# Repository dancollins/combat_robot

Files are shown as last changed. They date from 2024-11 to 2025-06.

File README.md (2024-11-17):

## Firmware

### Prerequisites

1. [Miniconda](https://docs.anaconda.com/miniconda/), and an environment with Python 3.10
2. [Zephyr SDK](https://docs.zephyrproject.org/latest/develop/toolchains/zephyr_sdk.html)
3. [CMake](https://cmake.org/download/)
4. [Ninja](https://ninja-build.org/)

Now you can run a few commands to get more dependancies:

    cd <repo>/zephyr-workspace
    west update
    cd zephyr/scripts
    pip install -r requirements.txt
    cd <repo>/zephyr-workspace

### Building

There's no actual firmware or board yet - so in the mean time here's a generic
build for the included minimal sample.

    west build --pristine --board nucleo_l412rb_p firmware

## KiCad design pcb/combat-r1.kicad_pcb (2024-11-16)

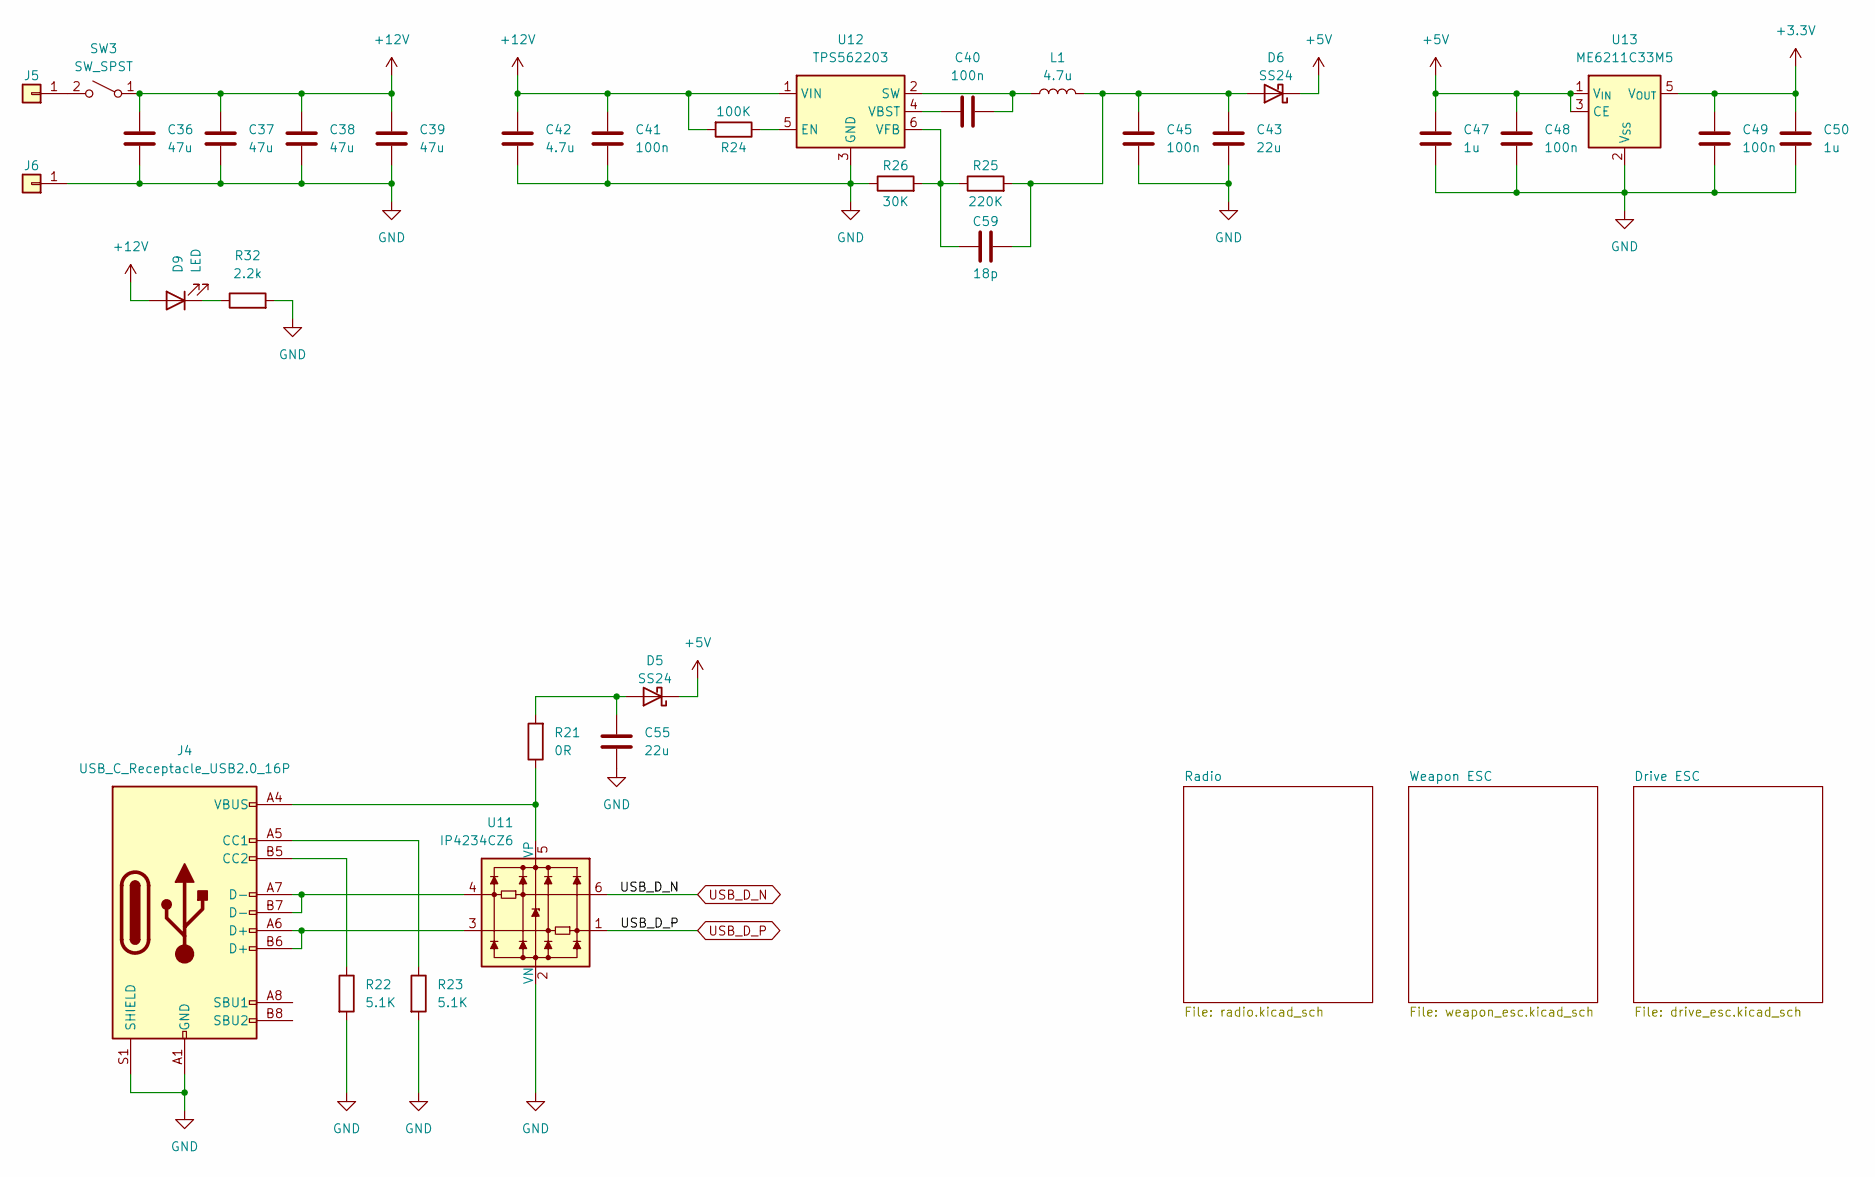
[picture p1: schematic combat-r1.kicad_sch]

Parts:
C36, C37, C38, C39: 47u; C_1210_3225Metric; LCSC C90142
C40, C41, C45, C48: 100n; C_0603_1608Metric; LCSC C1591
C42: 4.7u; C_0603_1608Metric; LCSC C69335
C43, C55: 22u; C_0805_2012Metric; LCSC C602037
C47: 1u; C_0603_1608Metric; Voltage 10V; LCSC C29936
C49: 100n; C_0603_1608Metric; Voltage 10V; LCSC C1591
C50: 1u; C_0603_1608Metric; LCSC C29936
C59: 18p; C_0603_1608Metric; LCSC C1647
D5, D6: SS24; D_SMA; LCSC C6069590
D9: LED; LED_0603_1608Metric; LCSC C434425
J4: USB_C_Receptacle_USB2.0_16P; USB_C_Receptacle_GCT_USB4105-xx-A_16P_TopMnt_Horizontal; LCSC C165948
J5, J6: Conn_01x01; SolderWire-1sqmm_1x01_D1.4mm_OD3.9mm
L1: 4.7u; L_Sunlord_MWSA0624S; LCSC C408433
R21: 0R; R_0603_1608Metric; LCSC C21189
R22, R23: 5.1K; R_0603_1608Metric; LCSC C23186
R24: 100K; R_0603_1608Metric; LCSC C25803
R25: 220K; R_0603_1608Metric; LCSC C22961
R26: 30K; R_0603_1608Metric; LCSC C22984
R32: 2.2k; R_0603_1608Metric; LCSC C4190
SW3: SW_SPST; m3-power-switch; LCSC C7528081
U11: IP4234CZ6; SC-74-6_1.55x2.9mm_P0.95mm; LCSC C551509
U12: TPS562203; SOT-563; LCSC C22445511
U13: ME6211C33M5; SOT-23-5; LCSC C82942

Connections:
+3.3V: C49.1, C50.1, U13.5 (V_{OUT}); also elsewhere on the board
+5V: C47.1, C48.1, D5.1 (K), D6.1 (K), U13.1 (V_{IN}), U13.3 (CE)
+12V: C36.1, C37.1, C38.1, C39.1, C41.1, C42.1, D9.2 (A), R24.2, SW3.1 (A), U12.1 (VIN); also elsewhere on the board
GND: C36.2, C37.2, C38.2, C39.2, C41.2, C42.2, C43.2, C45.2, C47.2, C48.2, C49.2, C50.2, C55.2, J4.A1 (GND), J4.A12 (GND), J4.B1 (GND), J4.B12 (GND), J4.S1 (SHIELD), J6.1, R22.2, R23.2, R26.1, R32.2, U11.2 (VN), U12.3 (GND), U13.2 (V_{SS}); also elsewhere on the board
unnamed: C55.1, D5.2 (A), R21.2
unnamed: C43.1, C45.1, C59.1, D6.2 (A), L1.2, R25.2
unnamed: D9.1 (K), R32.1
unnamed: J4.A5 (CC1), R23.1
unnamed: J4.B5 (CC2), R22.1
unnamed: J4.A6 (D+), J4.B6 (D+), U11.3
unnamed: J4.A7 (D-), J4.B7 (D-), U11.4
unnamed: J5.1, SW3.2 (B)
unnamed: J4.A4 (VBUS), J4.A9 (VBUS), J4.B4 (VBUS), J4.B9 (VBUS), R21.1, U11.5 (VP)
unnamed: R24.1, U12.5 (EN)
unnamed: C40.1, L1.1, U12.2 (SW)
unnamed: C40.2, U12.4 (VBST)
unnamed: C59.2, R25.1, R26.2, U12.6 (VFB)
USB_D_N: U11.6; also elsewhere on the board
USB_D_P: U11.1; also elsewhere on the board

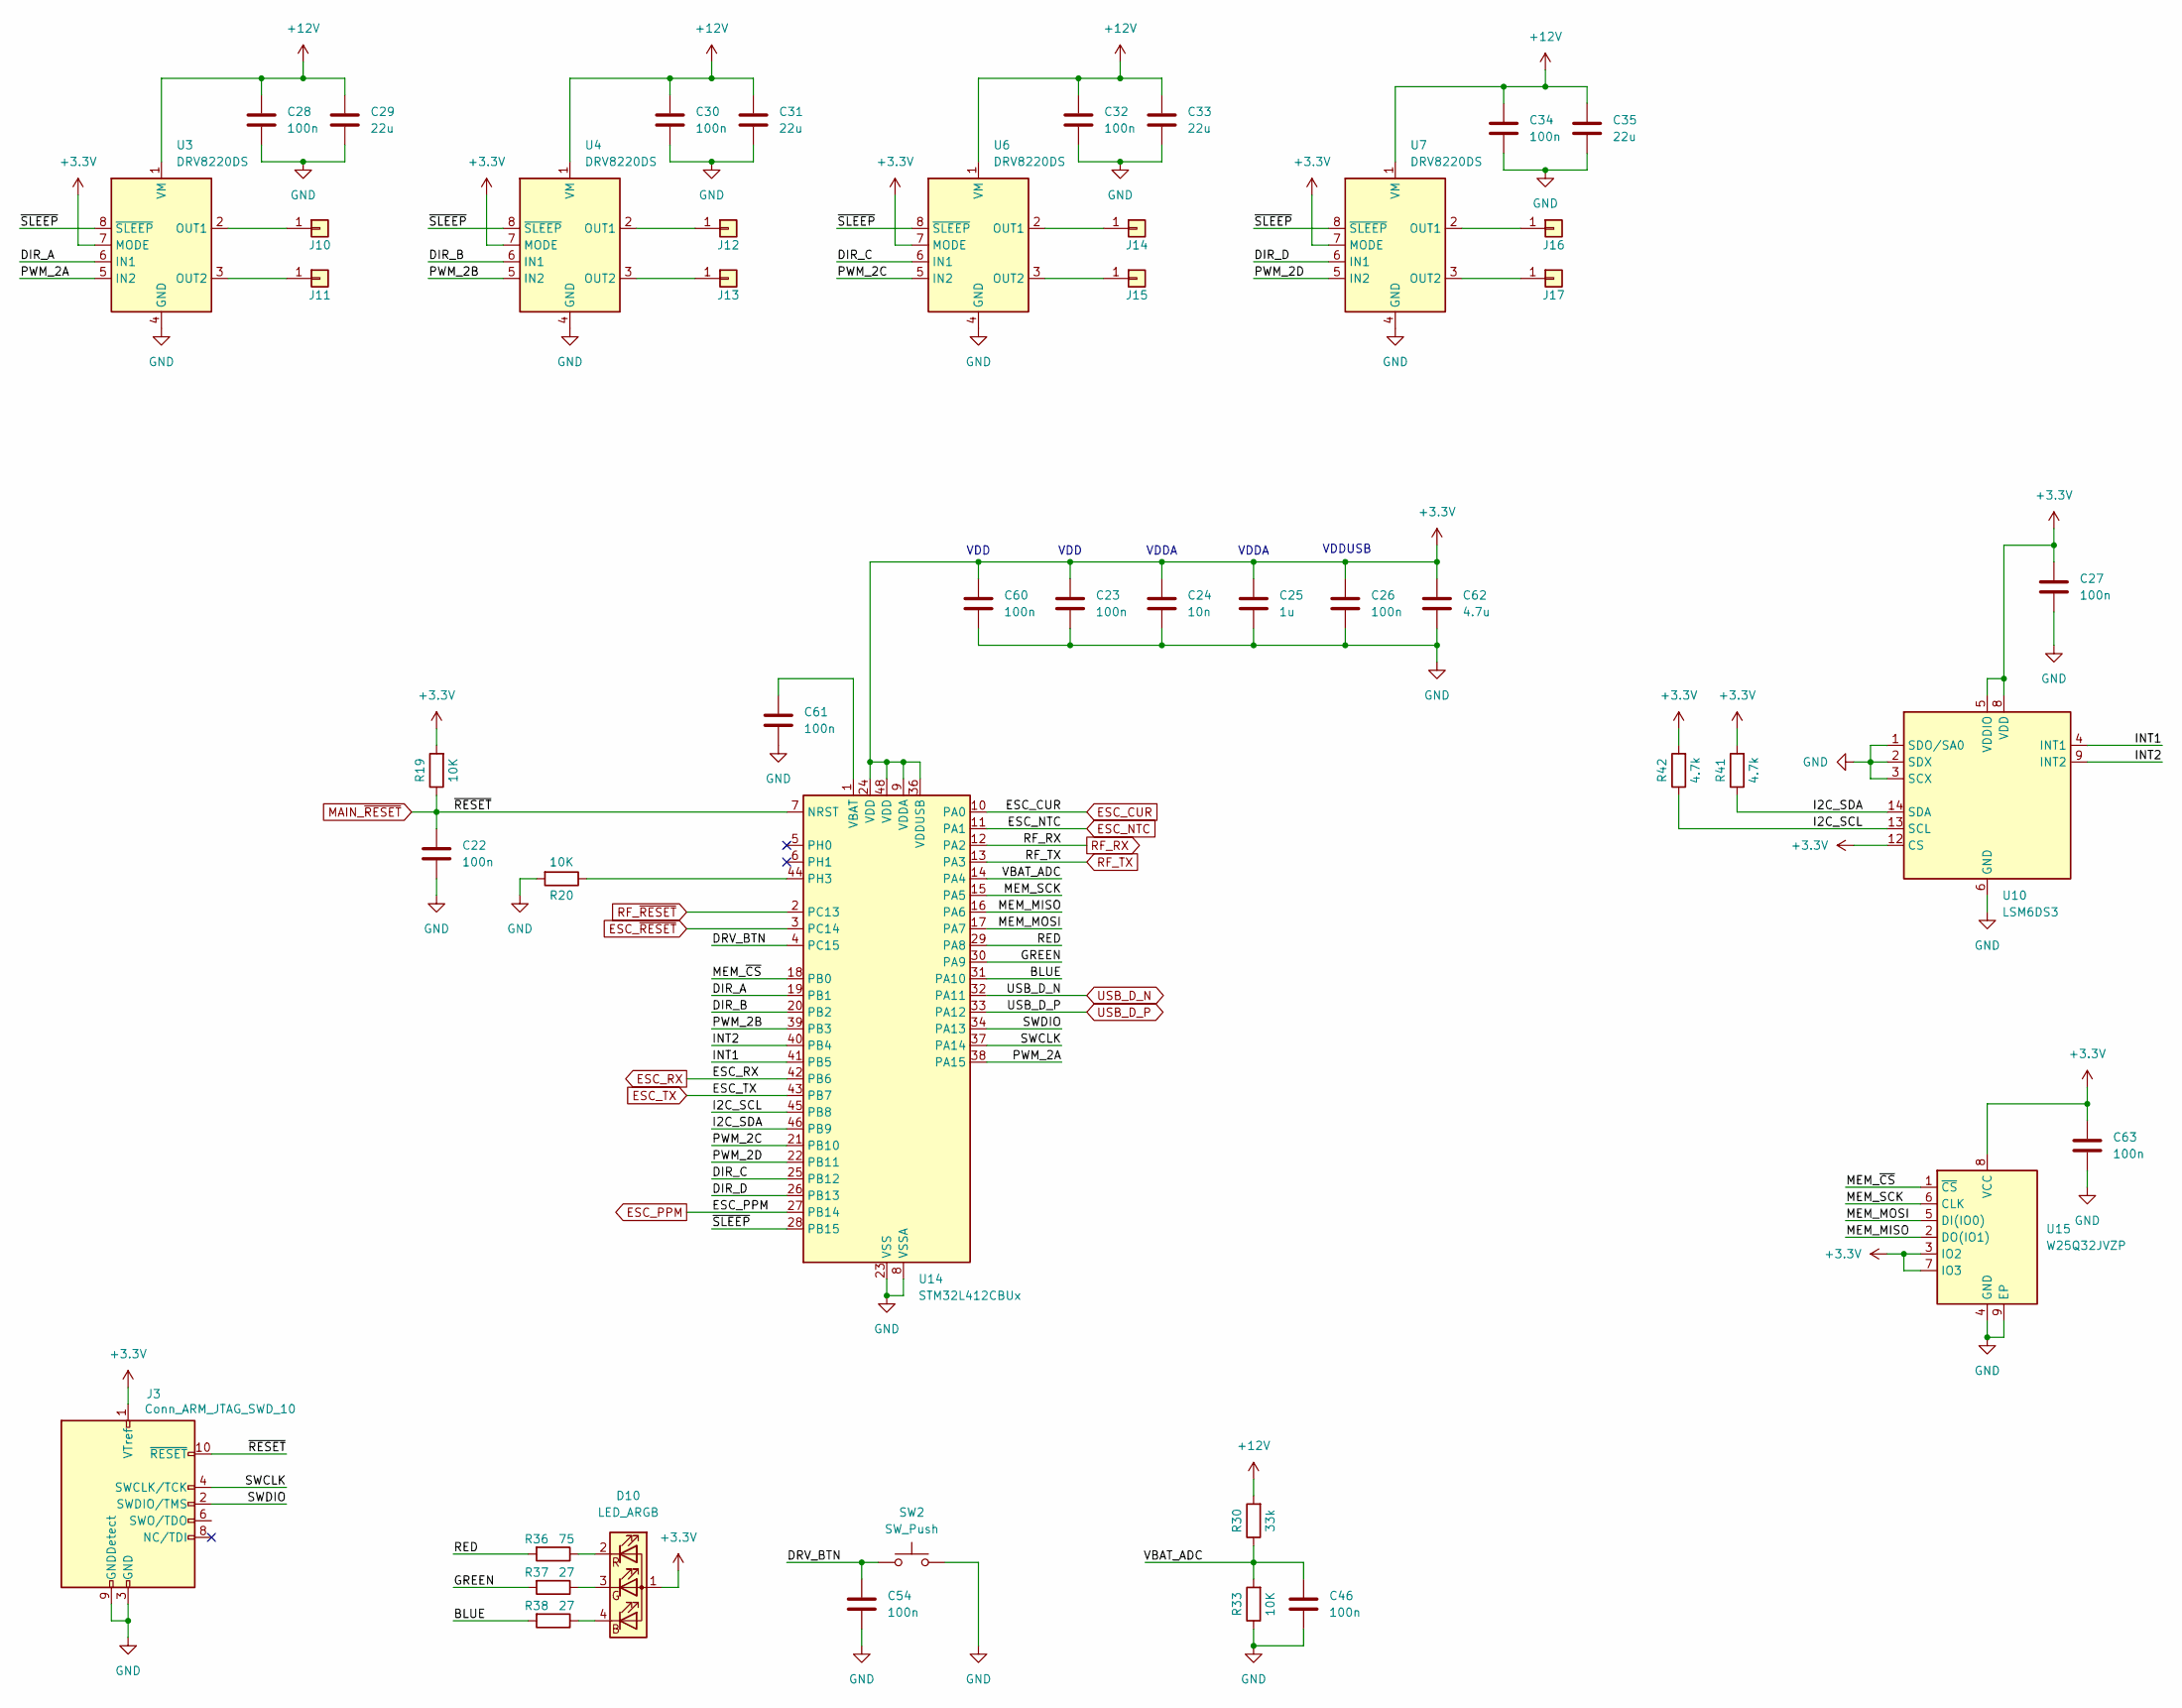
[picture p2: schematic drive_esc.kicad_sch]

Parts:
C22, C23, C26, C27, C28, C30, C32, C34, C46, C54, C60, C61, C63: 100n; C_0603_1608Metric; LCSC C1591
C24: 10n; C_0603_1608Metric; LCSC C1589
C25: 1u; C_0603_1608Metric; LCSC C29936
C29, C31, C33, C35: 22u; C_1206_3216Metric; LCSC C342620
C62: 4.7u; C_0603_1608Metric; LCSC C69335
D10: LED_ARGB; LED_LiteOn_LTST-C19HE1WT; LCSC C458749
J3: Conn_ARM_JTAG_SWD_10; PinHeader_2x05_P1.27mm_Vertical_SMD
J10, J11, J12, J13, J14, J15, J16, J17: Conn_01x01; SolderWire-1sqmm_1x01_D1.4mm_OD3.9mm
R19, R20, R33: 10K; R_0603_1608Metric; LCSC C25804
R30: 33k; R_0603_1608Metric; LCSC C4216
R36: 75; R_0603_1608Metric; LCSC C4275
R37, R38: 27; R_0603_1608Metric; LCSC C25190
R41, R42: 4.7k; R_0603_1608Metric; LCSC C23162
SW2: SW_Push; SW_SPST_Omron_B3FS-100xP; LCSC C4364467
U3, U4, U6, U7: DRV8220DS; WSON-8-1EP_2x2mm_P0.5mm_EP0.9x1.6mm; LCSC C3681269
U10: LSM6DS3; LGA-14_3x2.5mm_P0.5mm_LayoutBorder3x4y; LCSC C95230
U14: STM32L412CBUx; QFN-48-1EP_7x7mm_P0.5mm_EP5.6x5.6mm; Mouser 511-STM32L412C8U6
U15: W25Q32JVZP; WSON-8-1EP_6x5mm_P1.27mm_EP3.4x4.3mm; LCSC C571260

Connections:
+3.3V: C23.1, C24.1, C25.1, C26.1, C27.1, C60.1, C62.1, C63.1, D10.1 (A), J3.1 (VTref), R19.2, R41.2, R42.2, U3.7 (MODE), U4.7 (MODE), U6.7 (MODE), U7.7 (MODE), U10.5 (VDDIO), U10.8 (VDD), U10.12 (CS), U14.9 (VDDA), U14.24 (VDD), U14.36 (VDDUSB), U14.48 (VDD), U15.3 (IO2), U15.7 (IO3), U15.8 (VCC); also elsewhere on the board
+12V: C28.1, C29.1, C30.1, C31.1, C32.1, C33.1, C34.1, C35.1, R30.2, U3.1 (VM), U4.1 (VM), U6.1 (VM), U7.1 (VM); also elsewhere on the board
/Drive ESC/BLUE: R38.2, U14.31 (PA10)
/Drive ESC/DIR_A: U3.6 (IN1), U14.19 (PB1)
/Drive ESC/DIR_B: U4.6 (IN1), U14.20 (PB2)
/Drive ESC/DIR_C: U6.6 (IN1), U14.25 (PB12)
/Drive ESC/DIR_D: U7.6 (IN1), U14.26 (PB13)
/Drive ESC/DRV_BTN: C54.1, SW2.1, U14.4 (PC15)
/Drive ESC/GREEN: R37.2, U14.30 (PA9)
/Drive ESC/I2C_SCL: R42.1, U10.13 (SCL), U14.45 (PB8)
/Drive ESC/I2C_SDA: R41.1, U10.14 (SDA), U14.46 (PB9)
/Drive ESC/INT1: U10.4 (INT1), U14.41 (PB5)
/Drive ESC/INT2: U10.9 (INT2), U14.40 (PB4)
/Drive ESC/MEM_MISO: U14.16 (PA6), U15.2 (DO(IO1))
/Drive ESC/MEM_MOSI: U14.17 (PA7), U15.5 (DI(IO0))
/Drive ESC/MEM_SCK: U14.15 (PA5), U15.6 (CLK)
/Drive ESC/MEM_~CS: U14.18 (PB0), U15.1 (~CS)
/Drive ESC/PWM_2A: U3.5 (IN2), U14.38 (PA15)
/Drive ESC/PWM_2B: U4.5 (IN2), U14.39 (PB3)
/Drive ESC/PWM_2C: U6.5 (IN2), U14.21 (PB10)
/Drive ESC/PWM_2D: U7.5 (IN2), U14.22 (PB11)
/Drive ESC/RED: R36.2, U14.29 (PA8)
/Drive ESC/SWCLK: J3.4 (SWCLK/TCK), U14.37 (PA14)
/Drive ESC/SWDIO: J3.2 (SWDIO/TMS), U14.34 (PA13)
/Drive ESC/VBAT_ADC: C46.1, R30.1, R33.2, U14.14 (PA4)
/Drive ESC/~SLEEP: U3.8 (~SLEEP), U4.8 (~SLEEP), U6.8 (~SLEEP), U7.8 (~SLEEP), U14.28 (PB15)
ESC_CUR: U14.10 (PA0); also elsewhere on the board
ESC_NTC: U14.11 (PA1); also elsewhere on the board
ESC_PPM: U14.27 (PB14); also elsewhere on the board
ESC_RX: U14.42 (PB6); also elsewhere on the board
ESC_TX: U14.43 (PB7); also elsewhere on the board
ESC_~RESET: U14.3 (PC14); also elsewhere on the board
GND: C22.2, C23.2, C24.2, C25.2, C26.2, C27.2, C28.2, C29.2, C30.2, C31.2, C32.2, C33.2, C34.2, C35.2, C46.2, C54.2, C60.2, C61.2, C62.2, C63.2, J3.3 (GND), J3.5 (GND), J3.9 (GNDDetect), R20.2, R33.1, SW2.2, U3.4 (GND), U3.9 (GND), U4.4 (GND), U4.9 (GND), U6.4 (GND), U6.9 (GND), U7.4 (GND), U7.9 (GND), U10.1 (SDO/SA0), U10.2 (SDX), U10.3 (SCX), U10.6 (GND), U10.7 (GND), U14.8 (VSSA), U14.23 (VSS), U14.35 (VSS), U14.47 (VSS), U14.49 (VSS), U15.4 (GND), U15.9 (EP); also elsewhere on the board
MAIN_~RESET: C22.1, J3.10 (~RESET), R19.1, U14.7 (NRST)
unnamed: D10.4 (BK), R38.1
unnamed: D10.3 (GK), R37.1
unnamed: D10.2 (RK), R36.1
unnamed: J10.1, U3.2 (OUT1)
unnamed: J11.1, U3.3 (OUT2)
unnamed: J12.1, U4.2 (OUT1)
unnamed: J13.1, U4.3 (OUT2)
unnamed: J14.1, U6.2 (OUT1)
unnamed: J15.1, U6.3 (OUT2)
unnamed: J16.1, U7.2 (OUT1)
unnamed: J17.1, U7.3 (OUT2)
unnamed: R20.1, U14.44 (PH3)
unnamed: C61.1, U14.1 (VBAT)
RF_RX: U14.12 (PA2); also elsewhere on the board
RF_TX: U14.13 (PA3); also elsewhere on the board
RF_~RESET: U14.2 (PC13); also elsewhere on the board
USB_D_N: U14.32 (PA11); also elsewhere on the board
USB_D_P: U14.33 (PA12); also elsewhere on the board

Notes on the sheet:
VDDUSB
VDDA
VDD

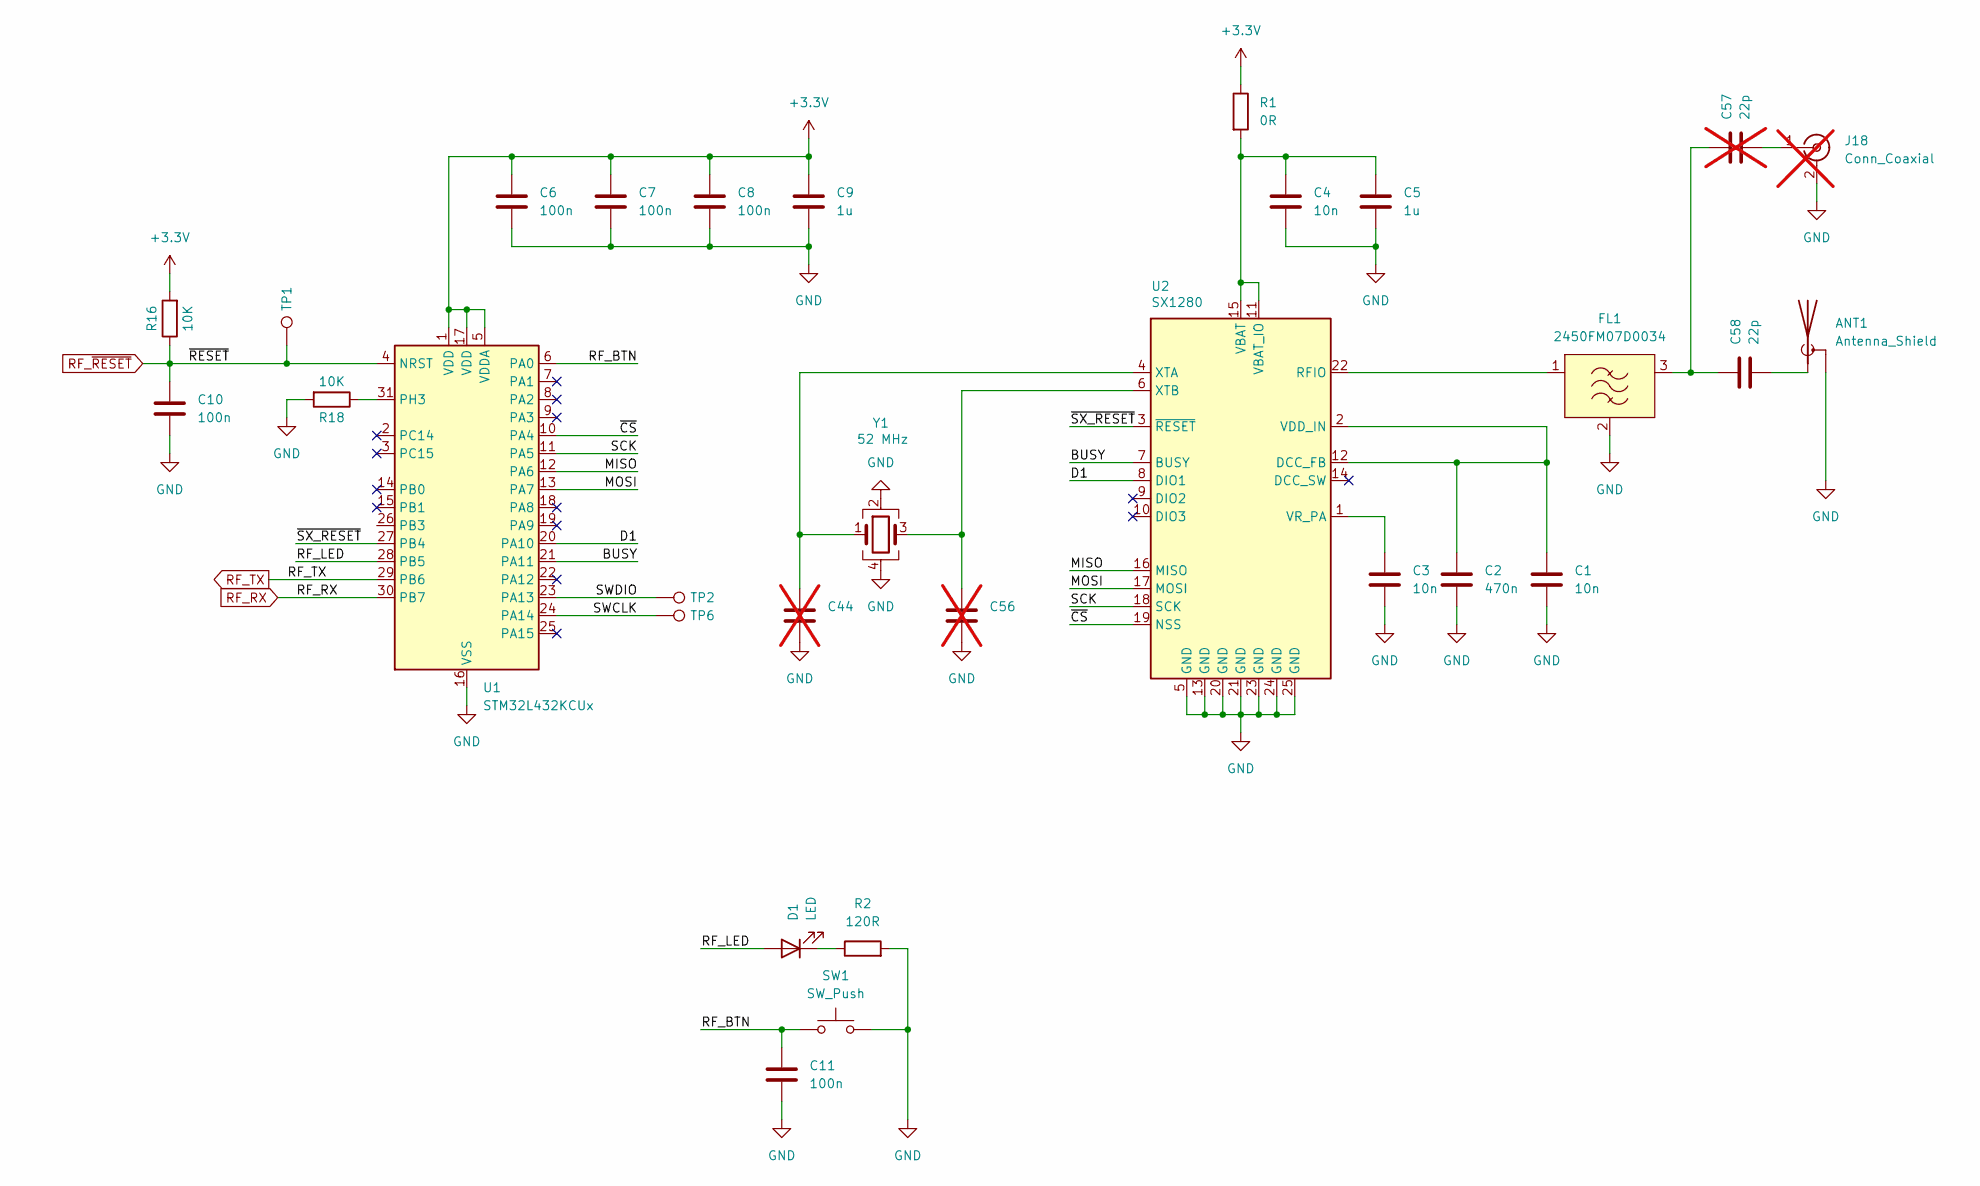
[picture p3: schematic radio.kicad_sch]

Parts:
ANT1: Antenna_Shield; Texas_SWRA117D_2.4GHz_Left
C1, C3, C4: 10n; C_0603_1608Metric; LCSC C1589
C2: 470n; C_0603_1608Metric; LCSC C1623
C5, C9: 1u; C_0603_1608Metric; LCSC C29936
C6, C7, C8, C10, C11: 100n; C_0603_1608Metric; LCSC C1591
C44, C56: C_0603_1608Metric; not fitted
C57: 22p; C_0603_1608Metric; LCSC C1653; not fitted
C58: 22p; C_0603_1608Metric; LCSC C1653
D1: LED; LED_0603_1608Metric; LCSC C965804
FL1: 2450FM07D0034; LCSC C2651081
J18: Conn_Coaxial; U.FL_Molex_MCRF_73412-0110_Vertical; LCSC C88374; not fitted
R1: 0R; R_0603_1608Metric; LCSC C21189
R2: 120R; R_0603_1608Metric; LCSC C22787
R16, R18: 10K; R_0603_1608Metric; LCSC C25804
SW1: SW_Push; SW_SPST_Omron_B3FS-100xP; LCSC C4364467
TP1, TP2, TP6: TestPoint; TestPoint_Pad_D2.0mm
U1: STM32L432KCUx; QFN-32-1EP_5x5mm_P0.5mm_EP3.45x3.45mm; LCSC C1337280
U2: SX1280; QFN-24-1EP_4x4mm_P0.5mm_EP2.7x2.7mm; LCSC C125969
Y1: 52 MHz; Crystal_SMD_2016-4Pin_2.0x1.6mm; LCSC C1986193

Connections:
+3.3V: C6.1, C7.1, C8.1, C9.1, R1.1, R16.2, U1.1 (VDD), U1.5 (VDDA), U1.17 (VDD); also elsewhere on the board
/Radio/BUSY: U1.21 (PA11), U2.7 (BUSY)
/Radio/D1: U1.20 (PA10), U2.8 (DIO1)
/Radio/MISO: U1.12 (PA6), U2.16 (MISO)
/Radio/MOSI: U1.13 (PA7), U2.17 (MOSI)
/Radio/RF_BTN: C11.1, SW1.1, U1.6 (PA0)
/Radio/RF_LED: D1.2 (A), U1.28 (PB5)
/Radio/SCK: U1.11 (PA5), U2.18 (SCK)
/Radio/SWCLK: TP6.1, U1.24 (PA14)
/Radio/SWDIO: TP2.1, U1.23 (PA13)
/Radio/~CS: U1.10 (PA4), U2.19 (NSS)
/Radio/~SX_RESET: U1.27 (PB4), U2.3 (~RESET)
GND: ANT1.2 (Shield), C1.2, C2.2, C3.2, C4.2, C5.2, C6.2, C7.2, C8.2, C9.2, C10.2, C11.2, C44.2, C56.2, FL1.2 (GND), FL1.4 (GND), J18.2 (Ext), R2.2, R18.2, SW1.2, U1.16 (VSS), U1.32 (VSS), U1.33 (VSS), U2.5 (GND), U2.13 (GND), U2.20 (GND), U2.21 (GND), U2.23 (GND), U2.24 (GND), U2.25 (GND), Y1.2, Y1.4; also elsewhere on the board
unnamed: ANT1.1 (A), C58.2
unnamed: D1.1 (K), R2.1
unnamed: FL1.1 (RF_IN), U2.22 (RFIO)
unnamed: C57.1, C58.1, FL1.3 (RF_OUT)
unnamed: C57.2, J18.1 (In)
unnamed: R18.1, U1.31 (PH3)
unnamed: C1.1, C2.1, U2.2 (VDD_IN), U2.12 (DCC_FB)
unnamed: C4.1, C5.1, R1.2, U2.11 (VBAT_IO), U2.15 (VBAT)
unnamed: C3.1, U2.1 (VR_PA)
unnamed: C44.1, U2.4 (XTA), Y1.1
unnamed: C56.1, U2.6 (XTB), Y1.3
RF_RX: U1.30 (PB7); also elsewhere on the board
RF_TX: U1.29 (PB6); also elsewhere on the board
RF_~RESET: C10.1, R16.1, TP1.1, U1.4 (NRST); also elsewhere on the board

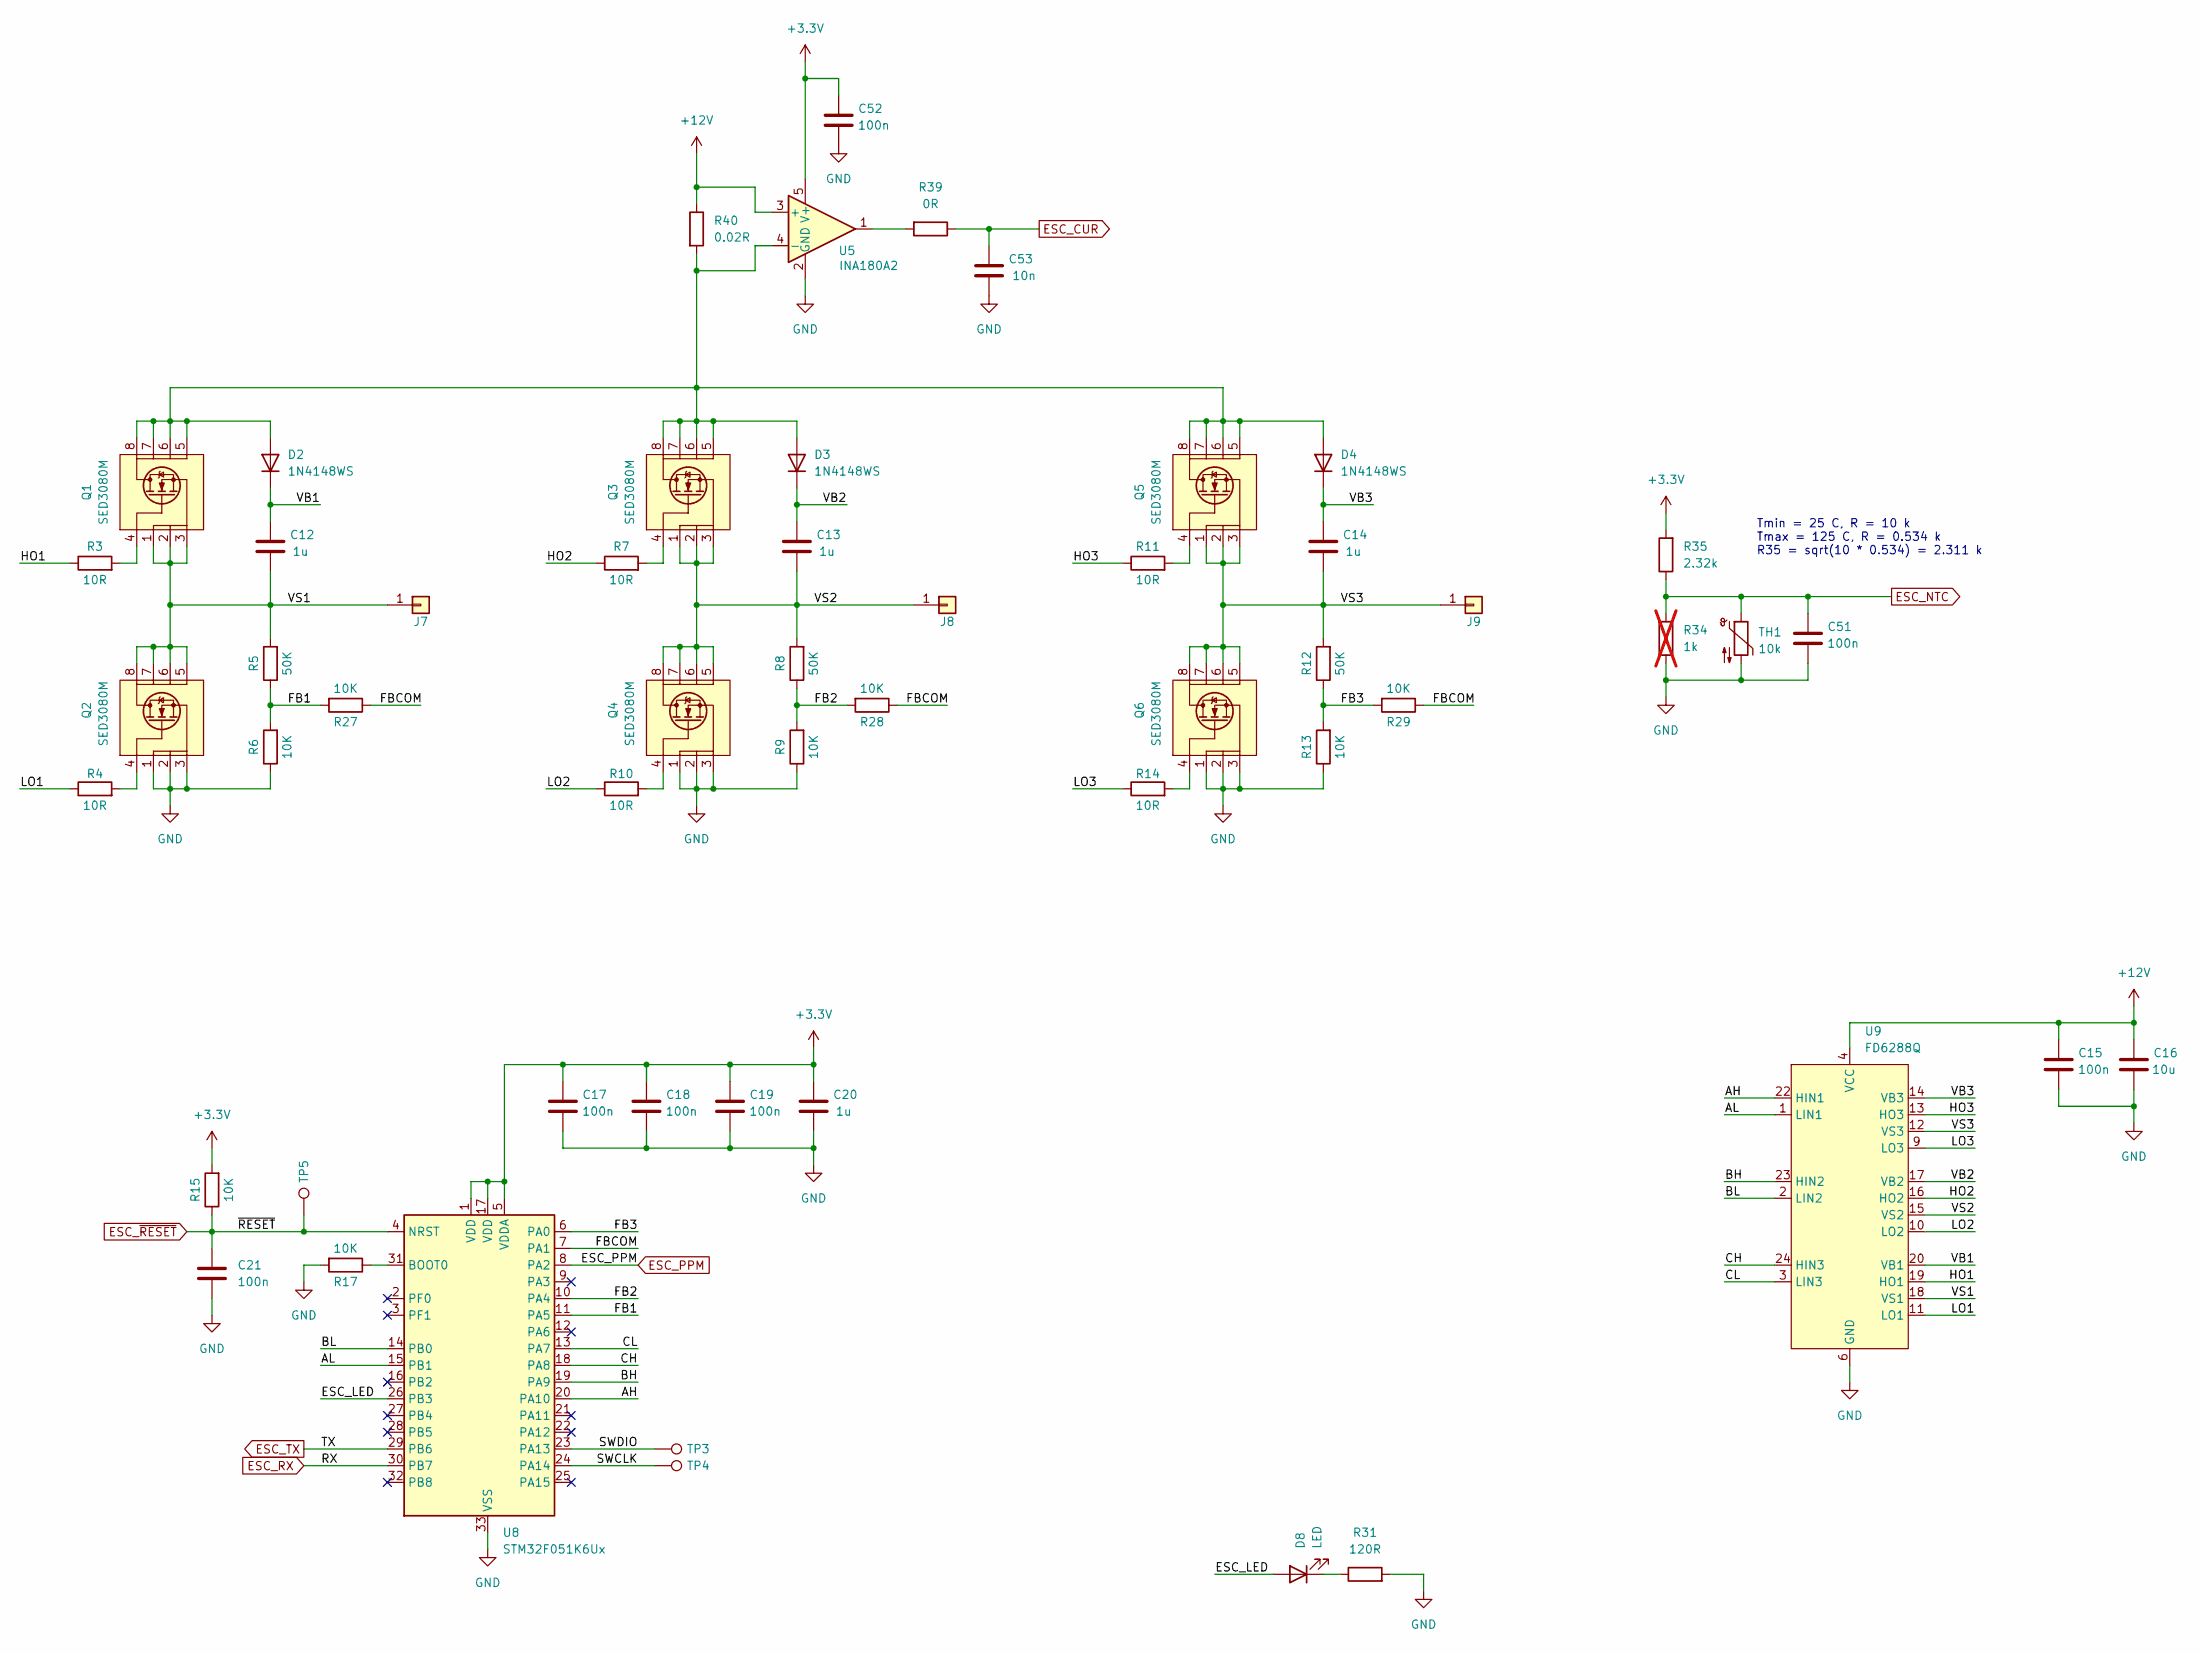
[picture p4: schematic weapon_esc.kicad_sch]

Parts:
C12, C13, C14, C20: 1u; C_0603_1608Metric; LCSC C29936
C15, C17, C18, C19, C21, C51, C52: 100n; C_0603_1608Metric; LCSC C1591
C16: 10u; C_0805_2012Metric; LCSC C440198
C53: 10n; C_0603_1608Metric; LCSC C1589
D2, D3, D4: 1N4148WS; D_SOD-323; LCSC C435854
D8: LED; LED_0603_1608Metric; LCSC C965804
J7, J8, J9: Conn_01x01; SolderWire-1sqmm_1x01_D1.4mm_OD3.9mm
Q1, Q2, Q3, Q4, Q5, Q6: SED3080M; DFN-8-SED3080M; LCSC C238667
R3, R4, R7, R10, R11, R14: 10R; R_0603_1608Metric; LCSC C22859
R5, R8, R12: 50K; R_0603_1608Metric; LCSC C304067
R6, R9, R13, R15, R17, R27, R28, R29: 10K; R_0603_1608Metric; LCSC C25804
R31: 120R; R_0603_1608Metric; LCSC C22787
R34: 1k; R_0603_1608Metric; LCSC C21190; not fitted
R35: 2.32k; R_0603_1608Metric; LCSC C22905
R39: 0R; R_0603_1608Metric; LCSC C21189
R40: 0.02R; R_1206_3216Metric; LCSC C723441
TH1: 10k; R_0603_1608Metric; LCSC C76589
TP3, TP4, TP5: TestPoint; TestPoint_Pad_D2.0mm
U5: INA180A2; SOT-23-5; LCSC C192764
U8: STM32F051K6Ux; QFN-32-1EP_5x5mm_P0.5mm_EP3.45x3.45mm; LCSC C81451
U9: FD6288Q; QFN-24-1EP_4x4mm_P0.5mm_EP2.65x2.65mm; LCSC C328453

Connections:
+3.3V: C17.1, C18.1, C19.1, C20.1, C52.1, R15.2, R35.2, U5.5 (V+), U8.1 (VDD), U8.5 (VDDA), U8.17 (VDD); also elsewhere on the board
+12V: C15.1, C16.1, R40.1, U5.3 (+), U9.4 (VCC); also elsewhere on the board
/Weapon ESC/AH: U8.20 (PA10), U9.22 (HIN1)
/Weapon ESC/AL: U8.15 (PB1), U9.1 (LIN1)
/Weapon ESC/BH: U8.19 (PA9), U9.23 (HIN2)
/Weapon ESC/BL: U8.14 (PB0), U9.2 (LIN2)
/Weapon ESC/CH: U8.18 (PA8), U9.24 (HIN3)
/Weapon ESC/CL: U8.13 (PA7), U9.3 (LIN3)
/Weapon ESC/ESC_LED: D8.2 (A), U8.26 (PB3)
/Weapon ESC/FB1: R5.1, R6.2, R27.2, U8.11 (PA5)
/Weapon ESC/FB2: R8.1, R9.2, R28.2, U8.10 (PA4)
/Weapon ESC/FB3: R12.1, R13.2, R29.2, U8.6 (PA0)
/Weapon ESC/FBCOM: R27.1, R28.1, R29.1, U8.7 (PA1)
/Weapon ESC/HO1: R3.1, U9.19 (HO1)
/Weapon ESC/HO2: R7.1, U9.16 (HO2)
/Weapon ESC/HO3: R11.1, U9.13 (HO3)
/Weapon ESC/LO1: R4.1, U9.11 (LO1)
/Weapon ESC/LO2: R10.1, U9.10 (LO2)
/Weapon ESC/LO3: R14.1, U9.9 (LO3)
/Weapon ESC/SWCLK: TP4.1, U8.24 (PA14)
/Weapon ESC/SWDIO: TP3.1, U8.23 (PA13)
/Weapon ESC/VB1: C12.1, D2.1 (K), U9.20 (VB1)
/Weapon ESC/VB2: C13.1, D3.1 (K), U9.17 (VB2)
/Weapon ESC/VB3: C14.1, D4.1 (K), U9.14 (VB3)
/Weapon ESC/VS1: C12.2, J7.1, Q1.1 (S), Q1.2 (S), Q1.3 (S), Q2.5 (D), Q2.6 (D), Q2.7 (D), Q2.8 (D), Q2.9, R5.2, U9.18 (VS1)
/Weapon ESC/VS2: C13.2, J8.1, Q3.1 (S), Q3.2 (S), Q3.3 (S), Q4.5 (D), Q4.6 (D), Q4.7 (D), Q4.8 (D), Q4.9, R8.2, U9.15 (VS2)
/Weapon ESC/VS3: C14.2, J9.1, Q5.1 (S), Q5.2 (S), Q5.3 (S), Q6.5 (D), Q6.6 (D), Q6.7 (D), Q6.8 (D), Q6.9, R12.2, U9.12 (VS3)
ESC_CUR: C53.1, R39.1; also elsewhere on the board
ESC_NTC: C51.1, R34.2, R35.1, TH1.1; also elsewhere on the board
ESC_PPM: U8.8 (PA2); also elsewhere on the board
ESC_RX: U8.30 (PB7); also elsewhere on the board
ESC_TX: U8.29 (PB6); also elsewhere on the board
ESC_~RESET: C21.1, R15.1, TP5.1, U8.4 (NRST); also elsewhere on the board
GND: C15.2, C16.2, C17.2, C18.2, C19.2, C20.2, C21.2, C51.2, C52.2, C53.2, Q2.1 (S), Q2.2 (S), Q2.3 (S), Q4.1 (S), Q4.2 (S), Q4.3 (S), Q6.1 (S), Q6.2 (S), Q6.3 (S), R6.1, R9.1, R13.1, R17.2, R31.2, R34.1, TH1.2, U5.2 (GND), U8.33 (VSS), U9.6 (GND), U9.25 (GND); also elsewhere on the board
unnamed: D2.2 (A), D3.2 (A), D4.2 (A), Q1.5 (D), Q1.6 (D), Q1.7 (D), Q1.8 (D), Q1.9, Q3.5 (D), Q3.6 (D), Q3.7 (D), Q3.8 (D), Q3.9, Q5.5 (D), Q5.6 (D), Q5.7 (D), Q5.8 (D), Q5.9, R40.2, U5.4 (-)
unnamed: D8.1 (K), R31.1
unnamed: Q1.4 (G), R3.2
unnamed: Q2.4 (G), R4.2
unnamed: Q3.4 (G), R7.2
unnamed: Q4.4 (G), R10.2
unnamed: Q5.4 (G), R11.2
unnamed: Q6.4 (G), R14.2
unnamed: R39.2, U5.1
unnamed: R17.1, U8.31 (BOOT0)

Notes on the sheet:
Tmin = 25 C, R = 10 k Tmax = 125 C, R = 0.534 k R35 = sqrt(10 * 0.534) = 2.311 k

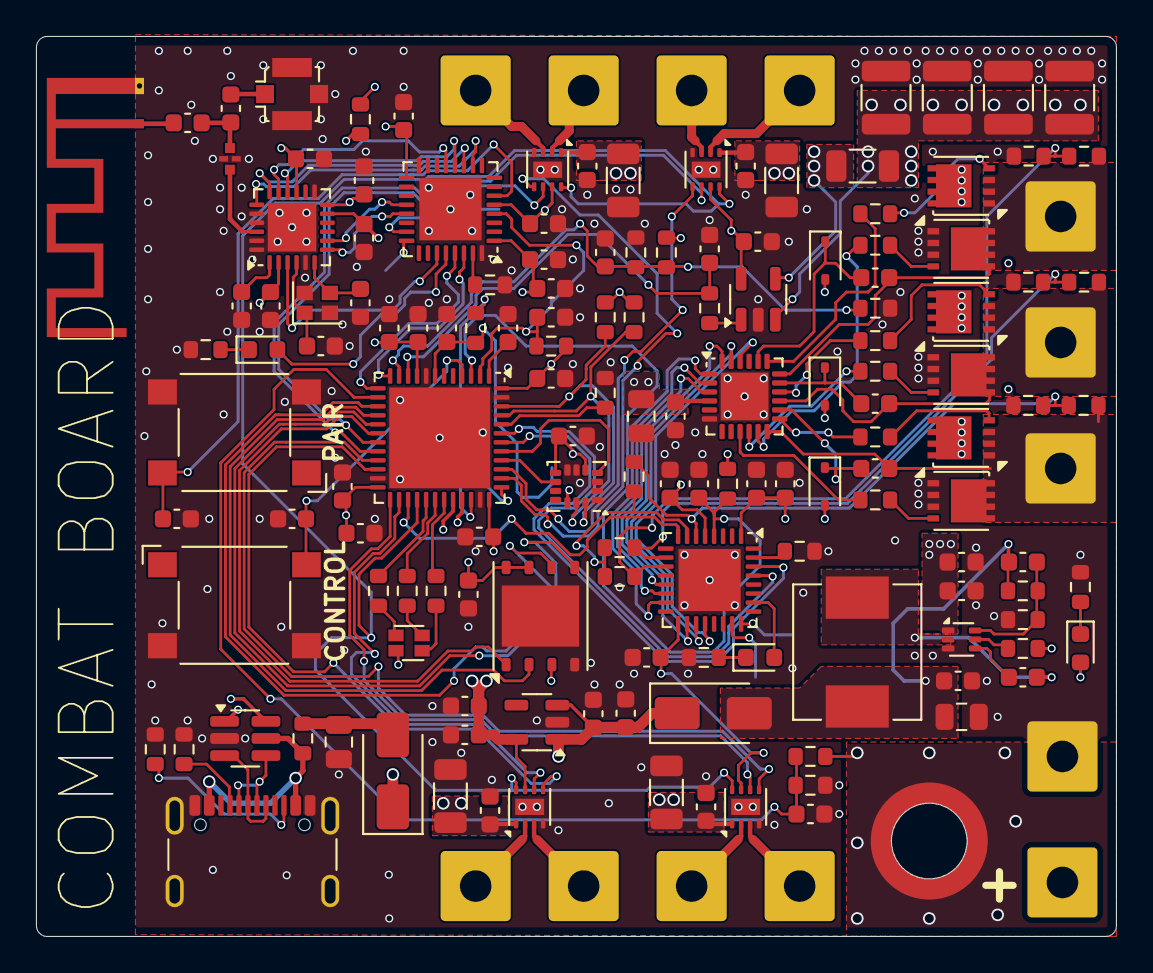
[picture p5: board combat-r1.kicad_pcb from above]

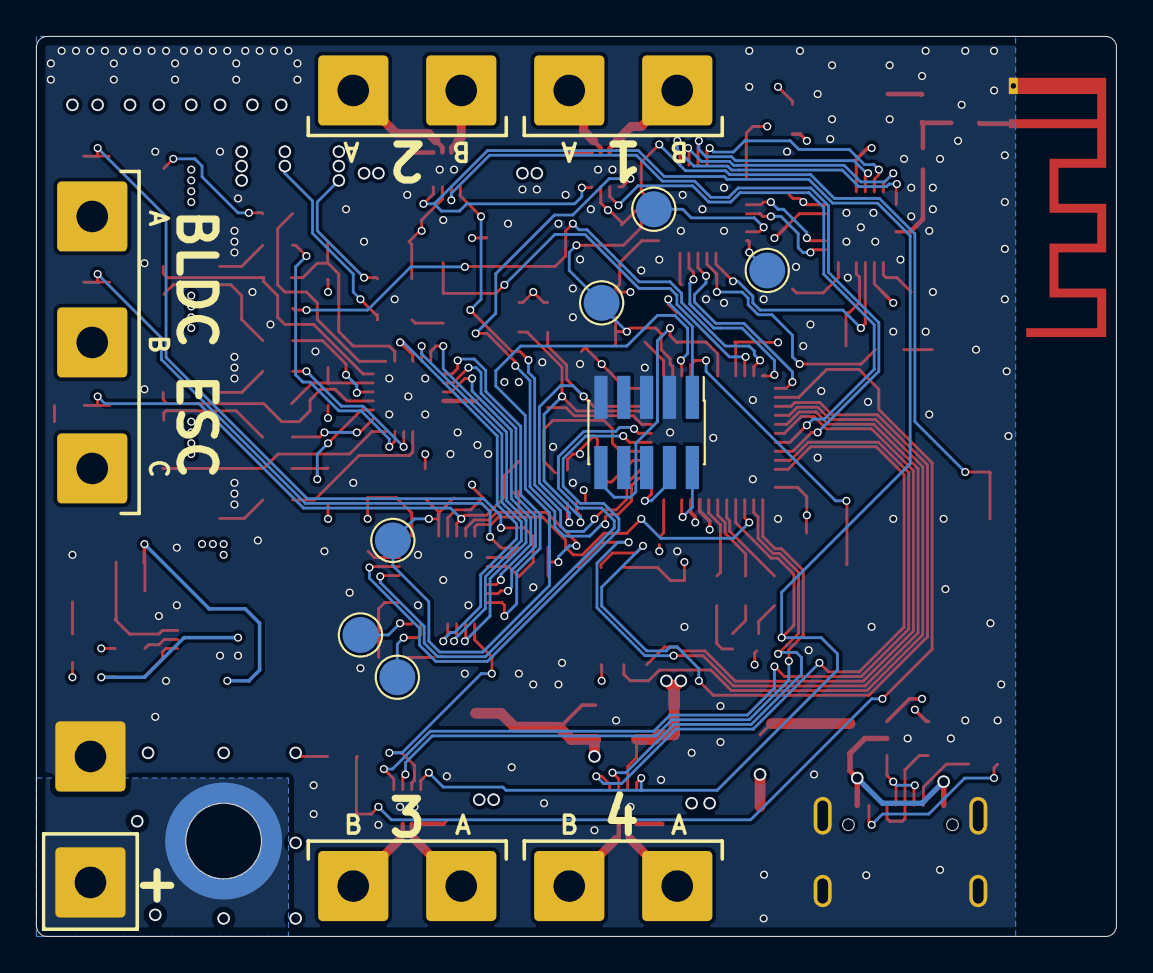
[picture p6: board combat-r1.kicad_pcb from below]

Board: 4 copper layers, 60.0 x 50.0 mm, 165 parts (7 on the bottom side), 123 nets.

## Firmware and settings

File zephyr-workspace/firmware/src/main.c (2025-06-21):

#include "main.h"

#include <math.h>
#include <string.h>
#include <zephyr/device.h>
#include <zephyr/drivers/flash.h>
#include <zephyr/drivers/gpio.h>
#include <zephyr/drivers/led.h>
#include <zephyr/drivers/pwm.h>
#include <zephyr/drivers/uart.h>
#include <zephyr/drivers/watchdog.h>
#include <zephyr/kernel.h>

#include "drivers/misc/csrf.h"

static const struct device *const wdt = DEVICE_DT_GET(DT_ALIAS(watchdog0));

static const struct device *elrs_radio =
    DEVICE_DT_GET(DT_NODELABEL(elrs_radio));

static const struct device *imu = DEVICE_DT_GET(DT_NODELABEL(accel_gyro));

static const struct pwm_dt_spec esc_pwm = PWM_DT_SPEC_GET(DT_NODELABEL(esc0));

static const struct pwm_dt_spec dc_motor_1 = PWM_DT_SPEC_GET(DT_NODELABEL(dc1));
static const struct pwm_dt_spec dc_motor_2 = PWM_DT_SPEC_GET(DT_NODELABEL(dc2));
static const struct pwm_dt_spec dc_motor_3 = PWM_DT_SPEC_GET(DT_NODELABEL(dc3));
static const struct pwm_dt_spec dc_motor_4 = PWM_DT_SPEC_GET(DT_NODELABEL(dc4));

static const struct gpio_dt_spec dc_motor_1_dir =
    GPIO_DT_SPEC_GET(DT_NODELABEL(dc_dir1), gpios);

static const struct gpio_dt_spec dc_motor_2_dir =
    GPIO_DT_SPEC_GET(DT_NODELABEL(dc_dir2), gpios);

static const struct gpio_dt_spec dc_motor_3_dir =
    GPIO_DT_SPEC_GET(DT_NODELABEL(dc_dir3), gpios);

static const struct gpio_dt_spec dc_motor_4_dir =
    GPIO_DT_SPEC_GET(DT_NODELABEL(dc_dir4), gpios);

static const struct gpio_dt_spec dc_motor_sleep =
    GPIO_DT_SPEC_GET(DT_NODELABEL(dc_sleep), gpios);

/* Work for killing the motors if the radio stops. */
static void stop_motors_work_handler(struct k_work *work);
K_WORK_DELAYABLE_DEFINE(stop_motors_work, stop_motors_work_handler);

static k_timeout_t stop_motors_timeout = K_MSEC(500);

static bool armed = false;

struct rcmix_data
{
    uint32_t fleft, rleft;
    bool fleft_dir, rleft_dir;

    uint32_t fright, rright;
    bool fright_dir, rright_dir;

    uint32_t weapon_pulse;
} rcmix_data;

static void update_channel_data(struct rcmix_data *data,
                                const struct csrf_channel_data *channels)
{
    /* RC channels run 0-2047.
     * Weapon ESC is 1000-2000 us.
     * DC motors are 0-20000 us. */

    static unsigned left_ch = 2;
    static unsigned right_ch = 1;
    static unsigned arm_btn = 7;
    static unsigned weapon_ch = 9;

    float left = channels->ch[left_ch] - 1024;
    float right = channels->ch[right_ch] - 1024;
    uint16_t weapon = channels->ch[weapon_ch];

    armed = channels->ch[arm_btn] > 1024;

    left = CLAMP(left / 1024.0f, -1.0f, 1.0f);
    right = CLAMP(right / 1024.0f, -1.0f, 1.0f);

    data->fleft = (uint32_t)(fabsf(left) * 20000000);
    data->fleft = CLAMP(data->fleft, 0, 20000000);

    data->fright = (uint32_t)(fabsf(right) * 20000000);
    data->fright = CLAMP(data->fright, 0, 20000000);

    data->rleft = data->fleft;
    data->rright = data->fright;

    if (left > 0) {
        data->fleft_dir = false;
        data->rleft_dir = false;
    } else {
        data->fleft_dir = true;
        data->rleft_dir = true;
    }

    if (right > 0) {
        data->fright_dir = true;
        data->rright_dir = true;
    } else {
        data->fright_dir = false;
        data->rright_dir = false;
    }

    const unsigned weapon_pulse_min = 1000000;
    const unsigned weapon_pulse_max = 2000000;

    data->weapon_pulse = (weapon * 500) + 1000000;
    data->weapon_pulse =
        CLAMP(data->weapon_pulse, weapon_pulse_min, weapon_pulse_max);

    if (armed) {
        led_set_state(LED_STATE_ARMED);
    } else {
        led_set_state(LED_STATE_DISARMED);
        data->weapon_pulse = weapon_pulse_min;
    }
}

static void csrf_channel_callback(const struct csrf_channel_data *channels)
{
    static unsigned count = 0;

    update_channel_data(&rcmix_data, channels);

    count++;
    if (count > 1000) {
        printk("ch");
        for (int i = 0; i < 16; i++) {
            printk(" %d", channels->ch[i]);
        }
        printk("\n");
        count = 0;
    }

    k_work_reschedule(&stop_motors_work, stop_motors_timeout);

    if (rcmix_data.fleft == 0 && rcmix_data.rleft == 0 &&
        rcmix_data.fright == 0 && rcmix_data.rright == 0) {
        gpio_pin_set_dt(&dc_motor_sleep, 1);
    } else {
        gpio_pin_set_dt(&dc_motor_sleep, 0);
    }

    /* Here's the mapping between logical channels and PWM channels! */
    gpio_pin_set_dt(&dc_motor_1_dir, rcmix_data.fleft_dir);
    gpio_pin_set_dt(&dc_motor_2_dir, !rcmix_data.fright_dir);
    gpio_pin_set_dt(&dc_motor_3_dir, rcmix_data.rright_dir);
    gpio_pin_set_dt(&dc_motor_4_dir, !rcmix_data.rleft_dir);

    pwm_set_pulse_dt(&dc_motor_1, rcmix_data.fleft);
    pwm_set_pulse_dt(&dc_motor_2, rcmix_data.fright);
    pwm_set_pulse_dt(&dc_motor_3, rcmix_data.rright);
    pwm_set_pulse_dt(&dc_motor_4, rcmix_data.rleft);

    pwm_set_pulse_dt(&esc_pwm, rcmix_data.weapon_pulse);
}

static void stop_motors_work_handler(struct k_work *work)
{
    pwm_set_pulse_dt(&dc_motor_1, 0);
    pwm_set_pulse_dt(&dc_motor_2, 0);
    pwm_set_pulse_dt(&dc_motor_3, 0);
    pwm_set_pulse_dt(&dc_motor_4, 0);

    pwm_set_pulse_dt(&esc_pwm, 1000000);

    led_set_state(LED_STATE_NO_RADIO);
}

static void init_watchdog(void)
{
    const unsigned wdt_min = 0;
    const unsigned wdt_max = 3000;

    int rc;

    if (!device_is_ready(wdt)) {
        printk("%s: device not ready.\n", wdt->name);
        return;
    }

    struct wdt_timeout_cfg wdt_config = {
        /* Reset SoC when watchdog timer expires. */
        .flags = WDT_FLAG_RESET_SOC,

        /* Expire watchdog after max window */
        .window.min = wdt_min,
        .window.max = wdt_max,
    };

    rc = wdt_install_timeout(wdt, &wdt_config);
    if (rc < 0) {
        printk("Failed to configure WDT.");
        return;
    }

    rc = wdt_setup(wdt, WDT_OPT_PAUSE_HALTED_BY_DBG);
    if (rc < 0) {
        printk("Failed to setup WDT.");
        return;
    }
}

int main(void)
{
    init_watchdog();

    if (!device_is_ready(elrs_radio)) {
        printk("ELRS radio device not ready\n");
    }

    if (!device_is_ready(imu)) {
        printk("IMU not ready\n");
    }

    printk("Hello, world!\n");

    csrf_set_channel_callback(elrs_radio, csrf_channel_callback);

    /* Zero out our speeds until we've got control data. */
    memset(&rcmix_data, 0, sizeof(rcmix_data));
    rcmix_data.weapon_pulse = 1000000;

    gpio_pin_set_dt(&dc_motor_sleep, 1);

    gpio_pin_set_dt(&dc_motor_1_dir, 0);
    gpio_pin_set_dt(&dc_motor_2_dir, 0);
    gpio_pin_set_dt(&dc_motor_3_dir, 0);
    gpio_pin_set_dt(&dc_motor_4_dir, 0);

    pwm_set_pulse_dt(&dc_motor_1, 0);
    pwm_set_pulse_dt(&dc_motor_2, 0);
    pwm_set_pulse_dt(&dc_motor_3, 0);
    pwm_set_pulse_dt(&dc_motor_4, 0);

    pwm_set_pulse_dt(&esc_pwm, 1000000);

    led_set_state(LED_STATE_NO_RADIO);

    while (1) {
        wdt_feed(wdt, 0);
        k_sleep(K_SECONDS(1));
    }

    return 0;
}

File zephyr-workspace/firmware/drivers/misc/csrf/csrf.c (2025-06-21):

#include <drivers/misc/csrf.h>
#include <zephyr/drivers/gpio.h>
#include <zephyr/drivers/uart.h>
#include <zephyr/kernel.h>
#include <zephyr/logging/log.h>
#include <zephyr/sys/byteorder.h>
#include <zephyr/sys/ring_buffer.h>

#define DT_DRV_COMPAT dan_csrf

LOG_MODULE_REGISTER(dan_csrf, CONFIG_DAN_CSRF_LOG_LEVEL);

enum rx_state
{
    RX_STATE_IDLE,
    RX_STATE_GET_LEN,
    RX_STATE_GET_TYPE,
    RX_STATE_CHECK_CRC
};

struct csrf_config
{
    const struct device *uart_dev;
    const struct gpio_dt_spec reset_gpio;
};

struct csrf_data
{
    const struct device *dev;

    csrf_channel_callback_t channel_callback;

    struct k_thread thread;
    K_KERNEL_STACK_MEMBER(thread_stack, CONFIG_DAN_CSRF_THREAD_STACK_SIZE);

    struct
    {
        struct ring_buf buf;
        uint8_t buf_data[CONFIG_DAN_CSRF_RX_BUFFER_SIZE];
        struct k_sem have_rx_data;

        enum rx_state state;
        uint8_t len;
        uint8_t type;
        uint8_t payload[64];
    } rx;
};

static uint8_t crc8tab[256] = {
    0x00, 0xD5, 0x7F, 0xAA, 0xFE, 0x2B, 0x81, 0x54, 0x29, 0xFC, 0x56, 0x83,
    0xD7, 0x02, 0xA8, 0x7D, 0x52, 0x87, 0x2D, 0xF8, 0xAC, 0x79, 0xD3, 0x06,
    0x7B, 0xAE, 0x04, 0xD1, 0x85, 0x50, 0xFA, 0x2F, 0xA4, 0x71, 0xDB, 0x0E,
    0x5A, 0x8F, 0x25, 0xF0, 0x8D, 0x58, 0xF2, 0x27, 0x73, 0xA6, 0x0C, 0xD9,
    0xF6, 0x23, 0x89, 0x5C, 0x08, 0xDD, 0x77, 0xA2, 0xDF, 0x0A, 0xA0, 0x75,
    0x21, 0xF4, 0x5E, 0x8B, 0x9D, 0x48, 0xE2, 0x37, 0x63, 0xB6, 0x1C, 0xC9,
    0xB4, 0x61, 0xCB, 0x1E, 0x4A, 0x9F, 0x35, 0xE0, 0xCF, 0x1A, 0xB0, 0x65,
    0x31, 0xE4, 0x4E, 0x9B, 0xE6, 0x33, 0x99, 0x4C, 0x18, 0xCD, 0x67, 0xB2,
    0x39, 0xEC, 0x46, 0x93, 0xC7, 0x12, 0xB8, 0x6D, 0x10, 0xC5, 0x6F, 0xBA,
    0xEE, 0x3B, 0x91, 0x44, 0x6B, 0xBE, 0x14, 0xC1, 0x95, 0x40, 0xEA, 0x3F,
    0x42, 0x97, 0x3D, 0xE8, 0xBC, 0x69, 0xC3, 0x16, 0xEF, 0x3A, 0x90, 0x45,
    0x11, 0xC4, 0x6E, 0xBB, 0xC6, 0x13, 0xB9, 0x6C, 0x38, 0xED, 0x47, 0x92,
    0xBD, 0x68, 0xC2, 0x17, 0x43, 0x96, 0x3C, 0xE9, 0x94, 0x41, 0xEB, 0x3E,
    0x6A, 0xBF, 0x15, 0xC0, 0x4B, 0x9E, 0x34, 0xE1, 0xB5, 0x60, 0xCA, 0x1F,
    0x62, 0xB7, 0x1D, 0xC8, 0x9C, 0x49, 0xE3, 0x36, 0x19, 0xCC, 0x66, 0xB3,
    0xE7, 0x32, 0x98, 0x4D, 0x30, 0xE5, 0x4F, 0x9A, 0xCE, 0x1B, 0xB1, 0x64,
    0x72, 0xA7, 0x0D, 0xD8, 0x8C, 0x59, 0xF3, 0x26, 0x5B, 0x8E, 0x24, 0xF1,
    0xA5, 0x70, 0xDA, 0x0F, 0x20, 0xF5, 0x5F, 0x8A, 0xDE, 0x0B, 0xA1, 0x74,
    0x09, 0xDC, 0x76, 0xA3, 0xF7, 0x22, 0x88, 0x5D, 0xD6, 0x03, 0xA9, 0x7C,
    0x28, 0xFD, 0x57, 0x82, 0xFF, 0x2A, 0x80, 0x55, 0x01, 0xD4, 0x7E, 0xAB,
    0x84, 0x51, 0xFB, 0x2E, 0x7A, 0xAF, 0x05, 0xD0, 0xAD, 0x78, 0xD2, 0x07,
    0x53, 0x86, 0x2C, 0xF9};

static void uart_callback(const struct device *dev, void *user_data)
{
    const struct device *csrf_dev = (const struct device *)user_data;
    struct csrf_data *data = csrf_dev->data;
    uint8_t ch;
    bool have_rx_data = false;

    /* Clear the error if there is one. */
    uart_err_check(dev);

    /* Acknowledge the interrupt, and then check if there's
     * actually work to do. */
    if ((uart_irq_update(dev) <= 0) || (uart_irq_rx_ready(dev) <= 0))
        return;

    while (uart_fifo_read(dev, &ch, 1) > 0) {
        ring_buf_put(&data->rx.buf, &ch, 1);
        have_rx_data = true;
    }

    if (have_rx_data) {
        k_sem_give(&data->rx.have_rx_data);
    }
}

static uint8_t csrf_crc8(const uint8_t *ptr, uint8_t len)
{
    uint8_t crc = 0;
    for (uint8_t i = 0; i < len; i++) crc = crc8tab[crc ^ *ptr++];
    return crc;
}

static void handle_rx_frame(struct csrf_data *data)
{
    k_sleep(K_MSEC(1));

    switch (data->rx.type) {
        case 0x16: {
            uint8_t *payload = data->rx.payload;
            struct csrf_channel_data channels;

            /* Each channel is 11 bits, so we need to unpack it all! */
            for (int i = 0; i < 16; i++) {
                uint32_t byte_index = (i * 11) / 8;
                uint32_t bit_offset = (i * 11) % 8;

                uint16_t val = (payload[byte_index] >> bit_offset) |
                               (payload[byte_index + 1] << (8 - bit_offset));

                /* Special case when our value spans 3 octets. */
                if (bit_offset > 5)
                    val |= payload[byte_index + 2] << (16 - bit_offset);

                val &= 0x07ff;

                channels.ch[i] = (int16_t)val;

                if (data->channel_callback)
                    data->channel_callback(&channels);
            }
            break;
        }
        default:
            break;
    }
}

static void process_buffer(struct csrf_data *data)
{
    uint32_t len;
    uint8_t buf[64];

    switch (data->rx.state) {
        case RX_STATE_IDLE:
            len = ring_buf_get(&data->rx.buf, buf, 1);
            if (len != 1)
                return;

            /* TODO handle other sync bytes */
            if (buf[0] != 0xc8)
                break;

            data->rx.state = RX_STATE_GET_LEN;
            break;

        case RX_STATE_GET_LEN:
            len = ring_buf_peek(&data->rx.buf, buf, 1);
            if (len != 1)
                return;

            if (buf[0] < 2 || buf[0] > 62) {
                ring_buf_get(&data->rx.buf, NULL, 1);
                data->rx.state = RX_STATE_IDLE;
            }

            data->rx.len = buf[0];
            data->rx.state = RX_STATE_GET_TYPE;
            break;

        case RX_STATE_GET_TYPE:
            /* Wait until we have a complete frame worth. */
            len = ring_buf_peek(&data->rx.buf, buf, data->rx.len + 1);
            if (len != data->rx.len + 1)
                return;

            /* TODO make sure it's a valid type. */
            data->rx.type = buf[1];
            data->rx.state = RX_STATE_CHECK_CRC;
            break;

        case RX_STATE_CHECK_CRC: {
            uint8_t expected, received;

            /* At this point, we're already figured out we have a complete
             * frame. if we don't, we'll reset the state! */
            len = ring_buf_peek(&data->rx.buf, buf, data->rx.len + 1);
            if (len != data->rx.len + 1) {
                data->rx.state = RX_STATE_IDLE;
                return;
            }

            expected = csrf_crc8(&buf[1], data->rx.len - 1);
            received = buf[data->rx.len];

            if (expected != received) {
                data->rx.state = RX_STATE_IDLE;
                return;
            }

            /* We have a valid frame! */
            memcpy(data->rx.payload, &buf[2], data->rx.len - 2);
            ring_buf_get(&data->rx.buf, NULL, data->rx.len + 1);
            data->rx.state = RX_STATE_IDLE;
            handle_rx_frame(data);
            break;
        }

        default:
            LOG_WRN("Invalid state %d", data->rx.state);
            data->rx.state = RX_STATE_IDLE;
            break;
    }
}
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

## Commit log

2024-11-16 initial commit, includes PCB
    [combat-r1-B_Cu.gbr, combat-r1-B_Mask.gbr, combat-r1-B_Silkscreen.gbr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]
2024-11-16 Adds ExpressLRS and checks out release with STM32
2024-11-16 Adds AM32 firmware for ESC
2024-11-18 Adds combat board device tree and updates main to load devices
    [combat_robot.yaml]
2024-11-18 adds skeleton for lsm6ds3 driver and littlefs
2024-11-18 Got lsm6ds3tr driver reading device ID
2024-11-18 Dropping littlefs to save about 25k of flash!
    We don't need it - the flash will be used for OTA of the
    radio and esc, and for storing sensor data. None of these
    cases depend on having a filesystem.
2024-11-18 Added tests for RGB LED and flash
2024-11-19 Adds skeleton CSRF driver
    Just prints out received characters. Hopefully enough to
    print data received from the transmitter...
2024-11-30 finished testing hardware, adds some CSRF decode
    This commit introduces the ESC and DC motor control.
    It also adds some basic frame decoding to the CSRF driver.
2024-11-30 app: added channels for DC motor, ESC and the red LED
2024-11-30 app: got channel mixing going - needs testing
    ... but to do that I need a chassis!
2025-06-21 adds missing files, switches to tank controls
    [csrf.c, main.c]
